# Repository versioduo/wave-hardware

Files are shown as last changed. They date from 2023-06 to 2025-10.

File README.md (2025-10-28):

# wave-hardware
🔊 MA12070P Class-D Amplifier

## Board

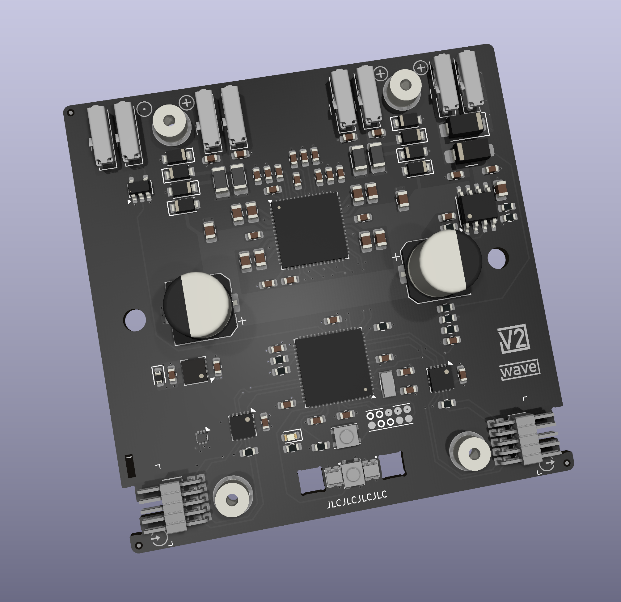
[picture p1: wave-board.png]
wave


## Schematic

[PDF](wave.pdf)

## Bill Of Materials

[Interactive BOM](https://htmlpreview.github.io/?https://github.com/versioduo/wave-hardware/main/wave-bom.html)

# Copying
Anyone can use this public domain work without having to seek authorisation, no one can ever own it.

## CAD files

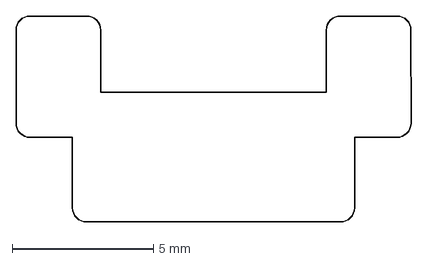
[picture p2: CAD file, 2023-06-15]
button-laser.dxf
14.0 x 7.30 mm

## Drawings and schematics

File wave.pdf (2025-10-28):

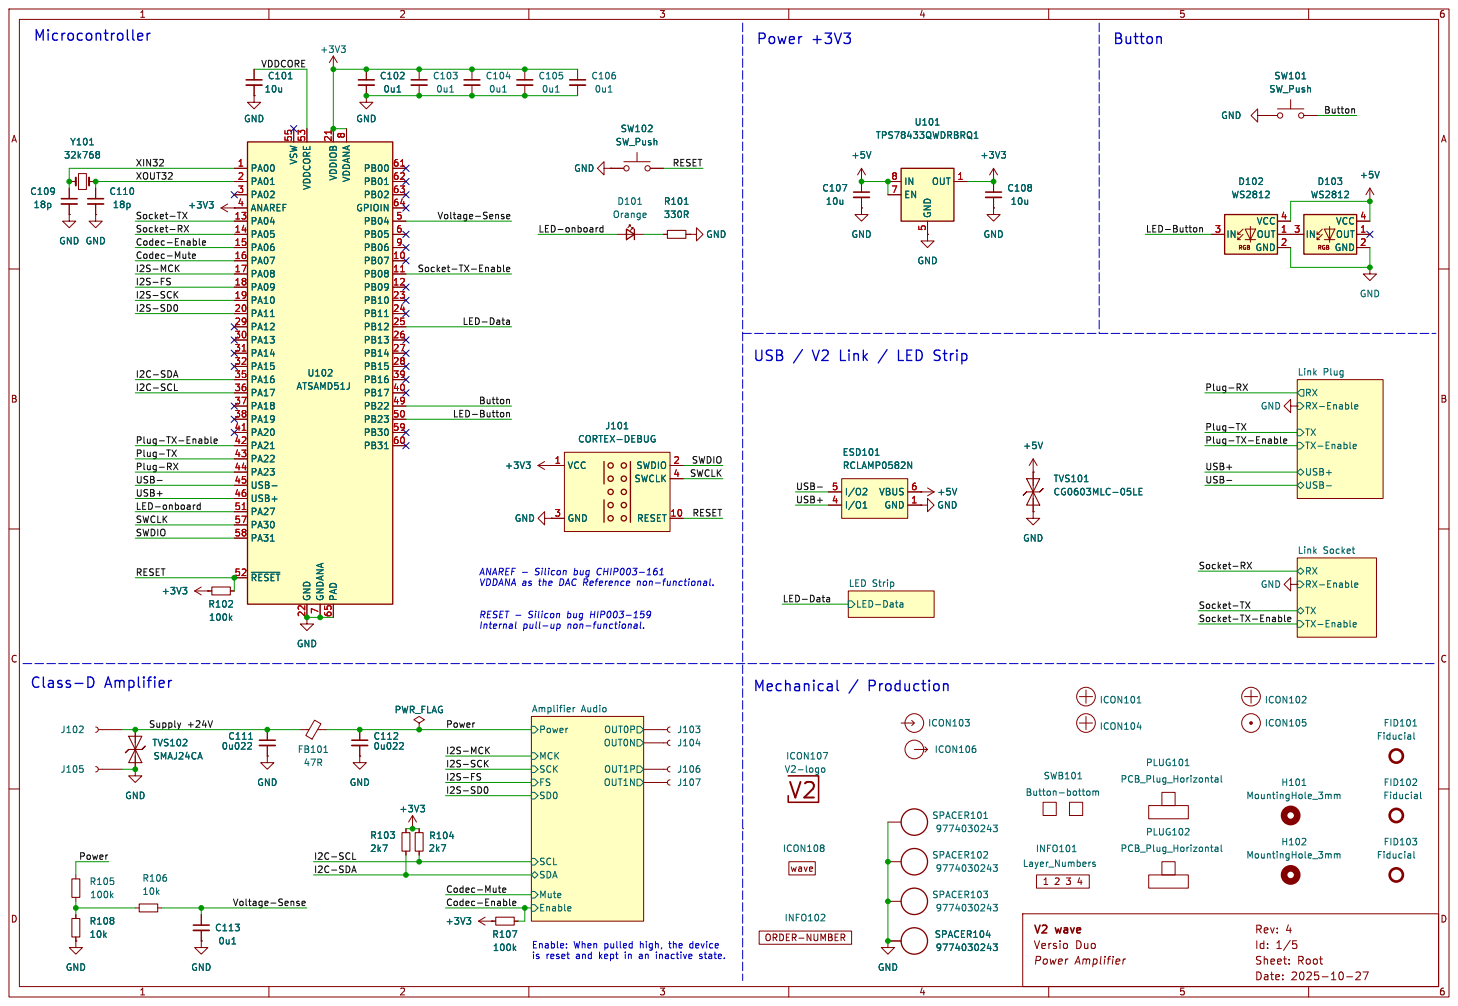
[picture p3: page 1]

LED-Data Socket-TX-Enable XIN32 XOUT32 Codec-Enable Socket-RX USB- Socket-TX USB+ Plug-RX

LED-Button Codec-Enable

Link Plug TXRXRX-Enable TX-Enable
USB+ USB- RX
TXRX-Enable TX-Enable

Plug-RX USB- SWDIO

Plug-TX USB+ RESET

Link Socket LED-Data

LED Strip Enable Mute SCL FS

Enable: When pulled high, the device

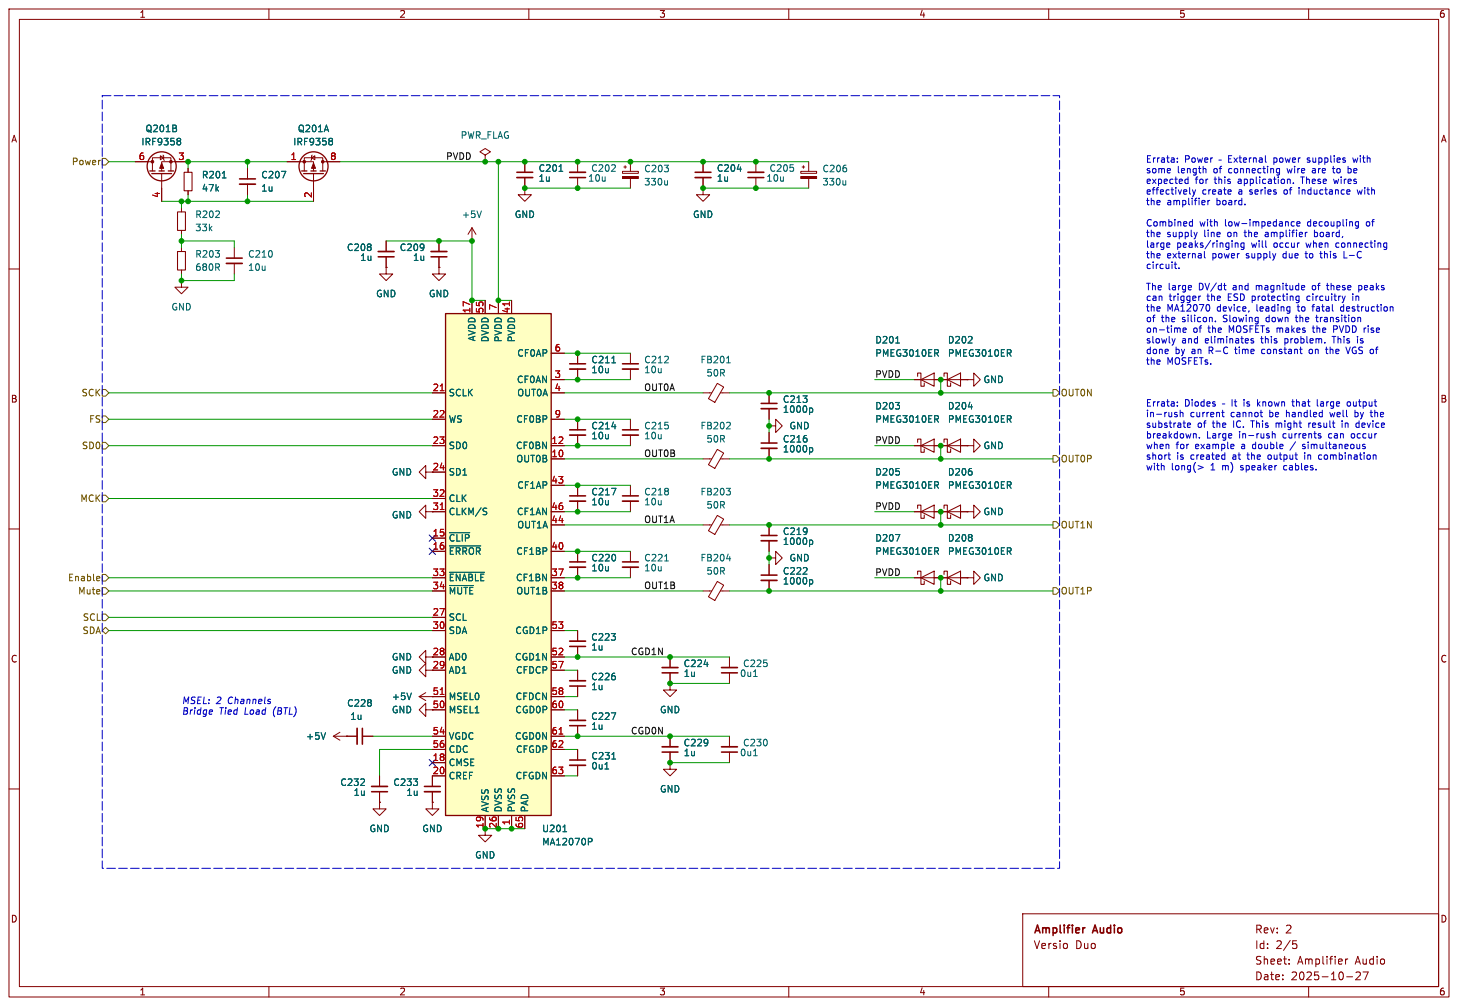
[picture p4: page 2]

PVDD MSEL: 2 Channels Bridge Tied Load (BTL)

the MA12070 device, leading to fatal destruction

1 PAD 65 CF0AP 6 CF0AN 3 OUT0A 4 CF0BP 9 CF0BN 12 OUT0B 10 CF1AP 43 CF1AN 46 OUT1A 44 CF1BP 40 CF1BN 37 OUT1B 38 CGD1P 53 CGD1N 52 CFDCP 57 CFDCN 58 CGD0P 60 CGD0N 61 CFGDP 62 CFGDN 63 C232

1 PAD 65 CF0AP 6 CF0AN 3 OUT0A 4 CF0BP 9 CF0BN 12 OUT0B 10 CF1AP 43 CF1AN 46 OUT1A 44 CF1BP 40 CF1BN 37 OUT1B 38 CGD1P 53 CGD1N 52 CFDCP 57 CFDCN 58 CGD0P 60 CGD0N 61 CFGDP 62 CFGDN 63 U201 MA12070P C233

the MOSFETs. Errata: Diodes þÿ It is known that large output

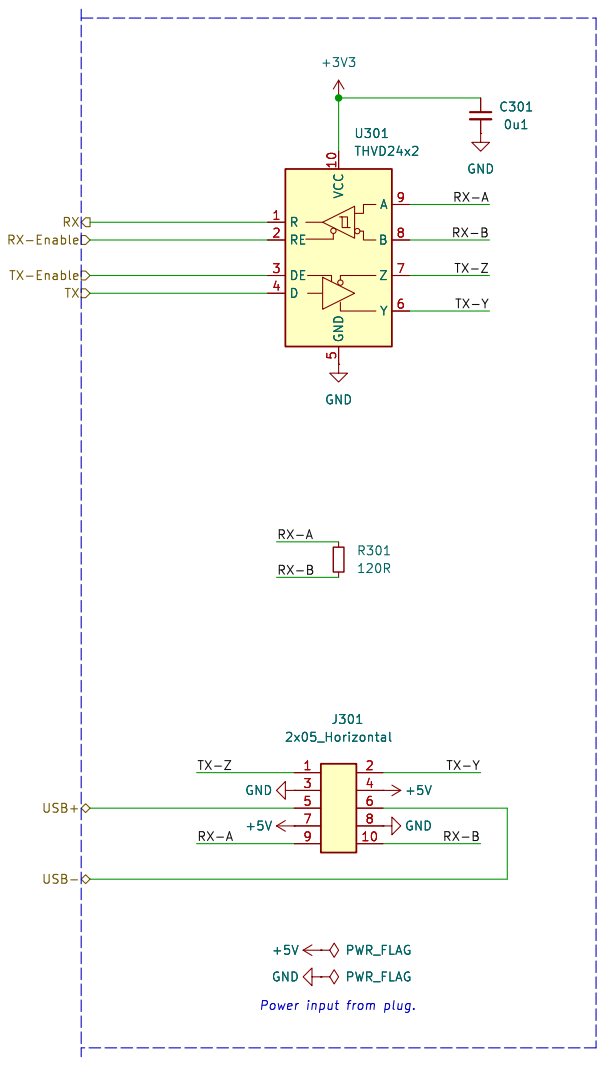
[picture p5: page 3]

Power input from plug. +5V GND GND

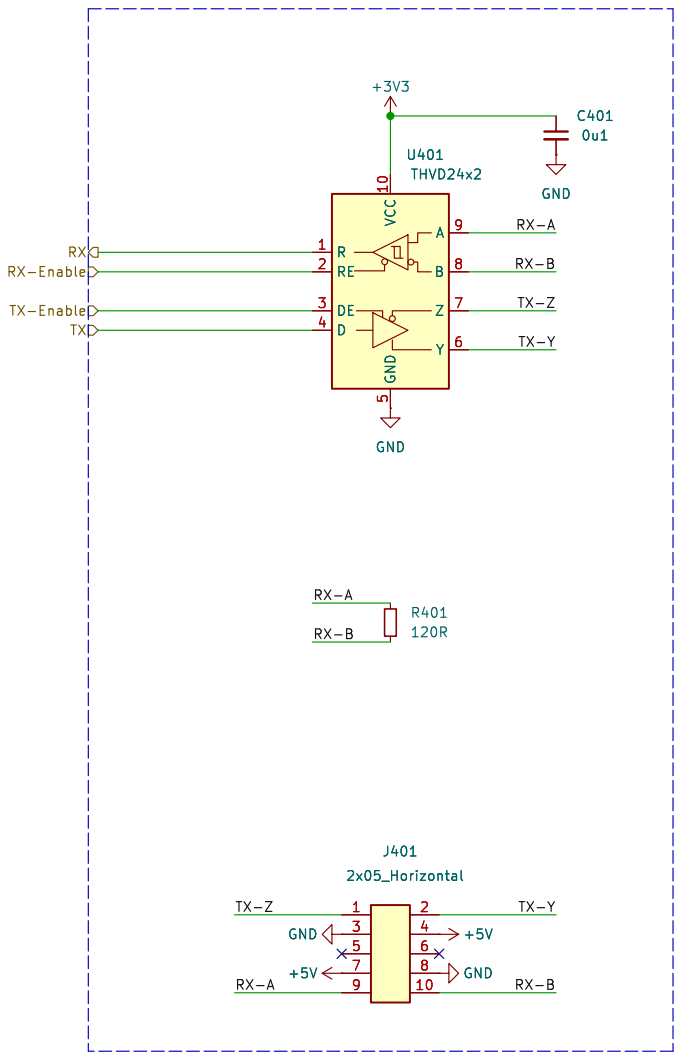
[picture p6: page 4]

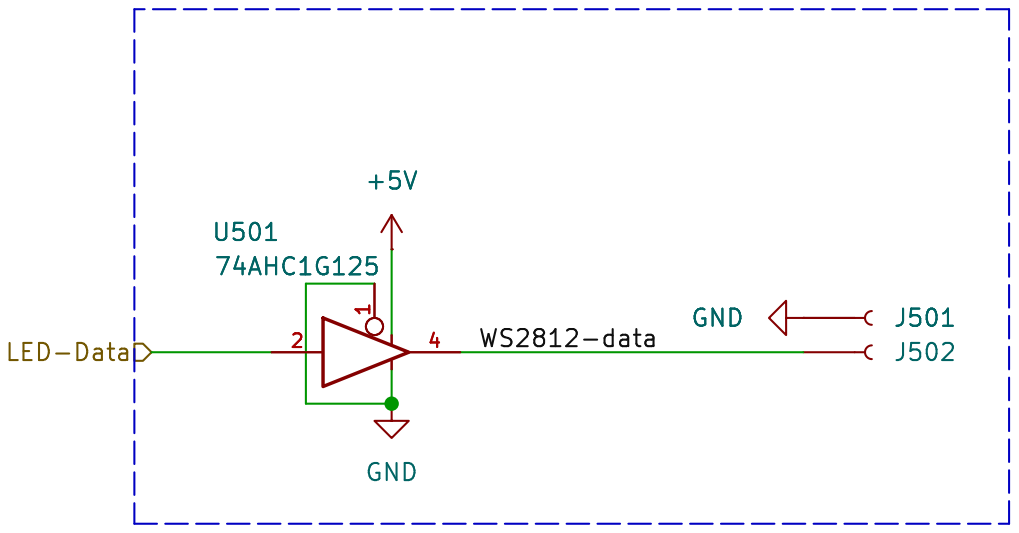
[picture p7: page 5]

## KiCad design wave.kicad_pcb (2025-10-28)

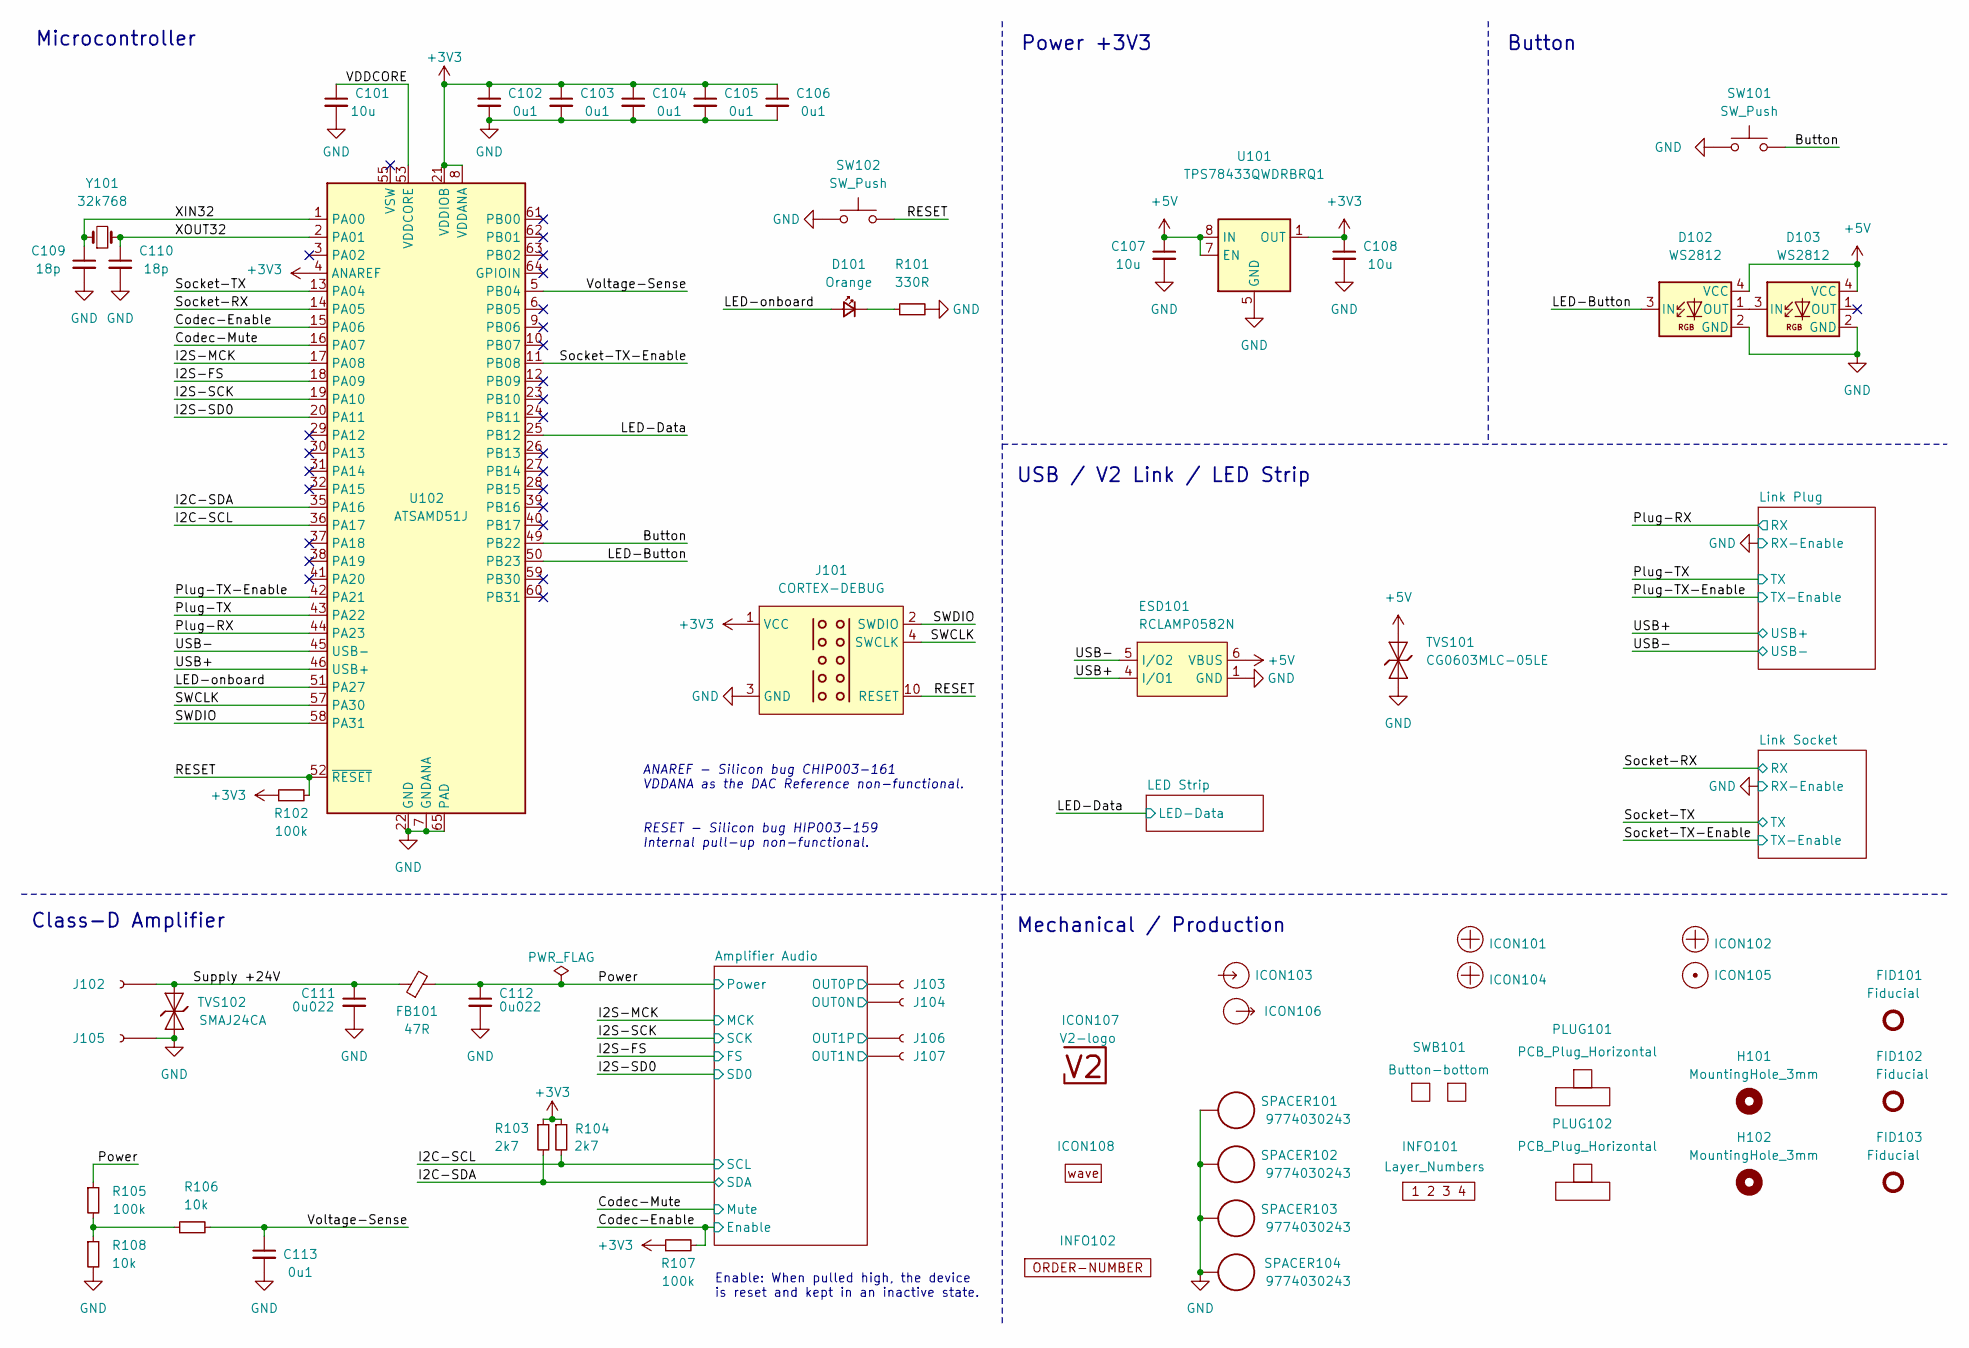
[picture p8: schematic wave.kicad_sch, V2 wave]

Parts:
C101, C107, C108: 10u; C_0603_1608Metric
C102, C103, C104, C105, C106, C113: 0u1; C_0603_1608Metric
C109, C110: 18p; C_0603_1608Metric
C111, C112: 0u022; C_0603_1608Metric
D101: Orange; LED_0603_1608Metric
D102, D103: WS2812; WS2812-2020
ESD101: RCLAMP0582N; SLP1210N6
FB101: 47R; L_3.1x5.1
FID101, FID102, FID103: Fiducial; Fiducial_0.5mm_Mask1mm_Paste
H101, H102: MountingHole_3mm
ICON101, ICON102, ICON104: Plus; Plus_Small
ICON103: Arrow_In
ICON105: Dot; Dot_Small
ICON106: Arrow_Out
ICON107: V2-logo; Logo_Small
ICON108: Board_wave; Board_wave_Small
INFO101: Layer_Numbers
INFO102: ORDER-NUMBER; Order_Number
J101: CORTEX-DEBUG; Cortex_Debug_Pad
J102, J103, J104, J105, J106, J107: WAGO-2065; 2065-100
PLUG101, PLUG102: PCB_Plug_Horizontal
R101: 330R; R_0603_1608Metric
R102, R105, R107: 100k; R_0603_1608Metric
R103, R104: 2k7; R_0603_1608Metric
R106, R108: 10k; R_0603_1608Metric
SPACER101, SPACER102, SPACER103, SPACER104: 9774030243
SW101, SW102: SW_Push; SKSG
SWB101: Button-bottom; PCB_Button-bottom
TVS101: CG0603MLC-05LE; D_0603_1608Metric
TVS102: SMAJ24CA; D_SMA
U101: TPS78433QWDRBRQ1; VSON-8-1_3x3mm_P0.65_EP1.65x2.4mm
U102: ATSAMD51J; QFN-64-1EP_9x9mm_P0.5mm_EP4.8x4.8mm_ThermalVias
Y101: 32k768; Crystal_SMD_3215-2Pin_3.2x1.5mm

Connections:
+3V3: C102.1, C103.1, C104.1, C105.1, C106.1, C108.1, J101.1 (VCC), R102.1, R103.1, R104.1, R107.1, U101.1 (OUT), U102.4 (ANAREF), U102.8 (VDDANA), U102.21 (VDDIOB), U102.34 (VDDIO), U102.48 (VDDIO), U102.56 (VDDIO); also elsewhere on the board
+5V: C107.1, D102.4 (VCC), D103.4 (VCC), ESD101.6 (VBUS), TVS101.2 (A), U101.7 (EN), U101.8 (IN); also elsewhere on the board
/Amplifier Audio/OUT0N: J104.1; also elsewhere on the board
/Amplifier Audio/OUT0P: J103.1; also elsewhere on the board
/Amplifier Audio/OUT1N: J107.1; also elsewhere on the board
/Amplifier Audio/OUT1P: J106.1; also elsewhere on the board
/Button: SW101.2, U102.49 (PB22)
/Codec-Enable: R107.2, U102.15 (PA06); also elsewhere on the board
/Codec-Mute: U102.16 (PA07); also elsewhere on the board
/I2C-SCL: R104.2, U102.36 (PA17); also elsewhere on the board
/I2C-SDA: R103.2, U102.35 (PA16); also elsewhere on the board
/I2S-FS: U102.18 (PA09); also elsewhere on the board
/I2S-MCK: U102.17 (PA08); also elsewhere on the board
/I2S-SCK: U102.19 (PA10); also elsewhere on the board
/I2S-SD0: U102.20 (PA11); also elsewhere on the board
/LED-Button: D102.3 (IN), U102.50 (PB23)
/LED-Data: U102.25 (PB12); also elsewhere on the board
/LED-onboard: D101.2 (A), U102.51 (PA27)
/Plug-RX: U102.44 (PA23); also elsewhere on the board
/Plug-TX: U102.43 (PA22); also elsewhere on the board
/Plug-TX-Enable: U102.42 (PA21); also elsewhere on the board
/Power: C112.1, FB101.2, R105.1; also elsewhere on the board
/RESET: J101.10 (RESET), R102.2, SW102.2, U102.52 (~RESET)
/SWCLK: J101.4 (SWCLK), U102.57 (PA30)
/SWDIO: J101.2 (SWDIO), U102.58 (PA31)
/Socket-RX: U102.14 (PA05); also elsewhere on the board
/Socket-TX: U102.13 (PA04); also elsewhere on the board
/Socket-TX-Enable: U102.11 (PB08); also elsewhere on the board
/Supply +24V: C111.1, FB101.1, J102.1, TVS102.2 (A)
/USB+: ESD101.4 (I/O1), U102.46 (USB+); also elsewhere on the board
/USB-: ESD101.5 (I/O2), U102.45 (USB-); also elsewhere on the board
/VDDCORE: C101.1, U102.53 (VDDCORE)
/Voltage-Sense: C113.1, R106.2, U102.5 (PB04)
/XIN32: C109.1, U102.1 (PA00), Y101.1
/XOUT32: C110.1, U102.2 (PA01), Y101.2
GND: C101.2, C102.2, C103.2, C104.2, C105.2, C106.2, C107.2, C108.2, C109.2, C110.2, C111.2, C112.2, C113.2, D102.2 (GND), D103.2 (GND), ESD101.1 (GND), J101.3 (GND), J101.5 (GND), J105.1, R101.2, R108.2, SPACER101.1, SPACER102.1, SPACER103.1, SPACER104.1, SW101.1, SW102.1, TVS101.1 (K), TVS102.1 (K), U101.5 (GND), U101.9 (GND), U102.7 (GNDANA), U102.22 (GND), U102.33 (GND), U102.47 (GND), U102.54 (GND), U102.65 (PAD); also elsewhere on the board
unnamed: D101.1 (K), R101.1
unnamed: D102.1 (OUT), D103.3 (IN)
unnamed: R105.2, R106.1, R108.1

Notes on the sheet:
 ANAREF - Silicon bug CHIP003-161 VDDANA as the DAC Reference non-functional.
RESET -  Silicon bug HIP003-159 Internal pull-up non-functional.
Button
USB / V2 Link / LED Strip
Mechanical / Production
Power +3V3
Enable: When pulled high, the device is reset and kept in an inactive state.
Microcontroller
Class-D Amplifier

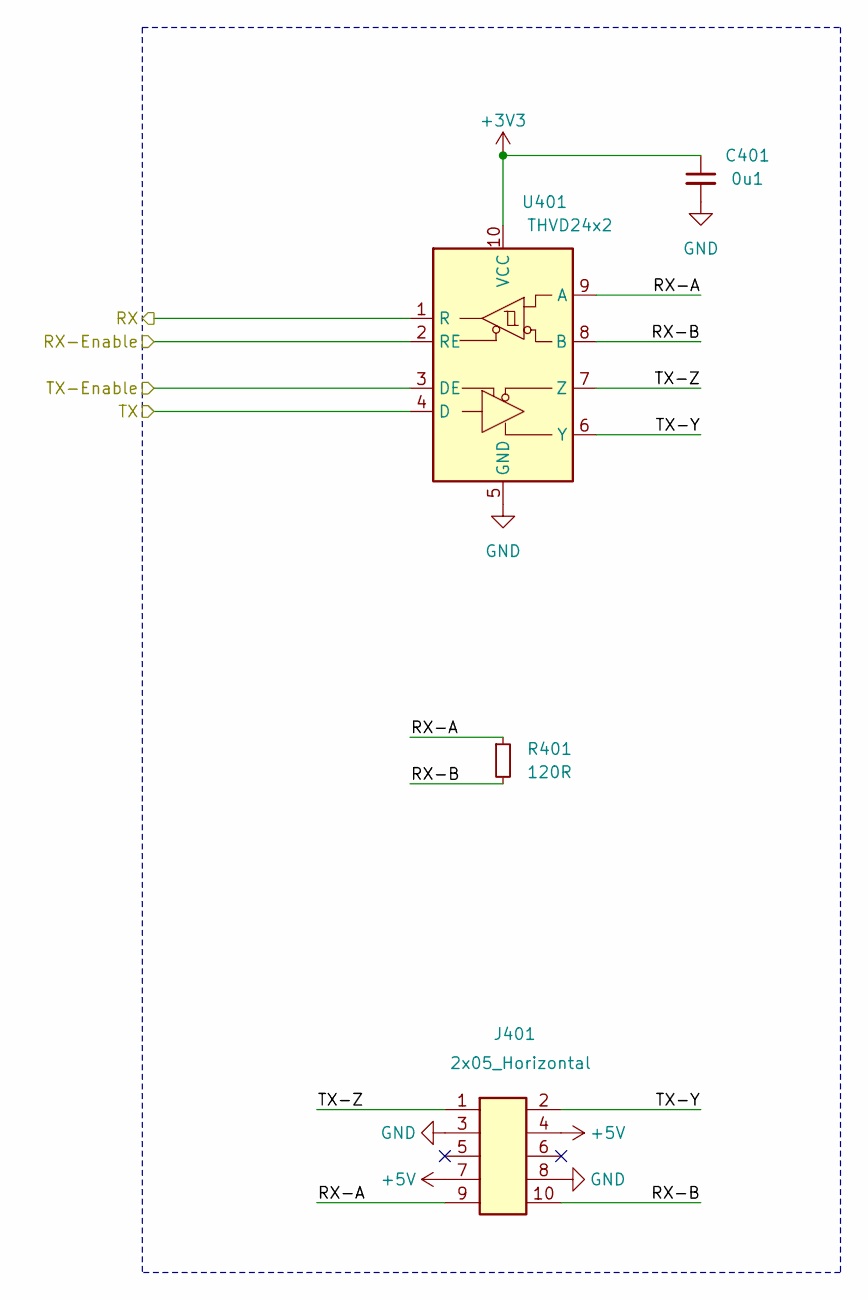
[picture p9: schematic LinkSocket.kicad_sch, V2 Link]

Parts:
C401: 0u1; C_0603_1608Metric
J401: 2x05_Horizontal; PinHeader_2x05_P1.27mm_Horizontal
R401: 120R; R_0603_1608Metric
U401: THVD24x2; VSON-10-4-1EP_3x3mm_P0.5mm_EP1.65x2.4mm_ThermalVias

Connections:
+3V3: C401.1, U401.10 (VCC); also elsewhere on the board
+5V: J401.4, J401.7; also elsewhere on the board
/Link Socket/RX-A: J401.9, R401.1, U401.9 (A)
/Link Socket/RX-B: J401.10, R401.2, U401.8 (B)
/Link Socket/TX-Y: J401.2, U401.6 (Y)
/Link Socket/TX-Z: J401.1, U401.7 (Z)
/Socket-RX: U401.1 (R); also elsewhere on the board
/Socket-TX: U401.4 (D); also elsewhere on the board
/Socket-TX-Enable: U401.3 (DE); also elsewhere on the board
GND: C401.2, J401.3, J401.8, U401.2 (RE), U401.5 (GND), U401.11 (GND); also elsewhere on the board

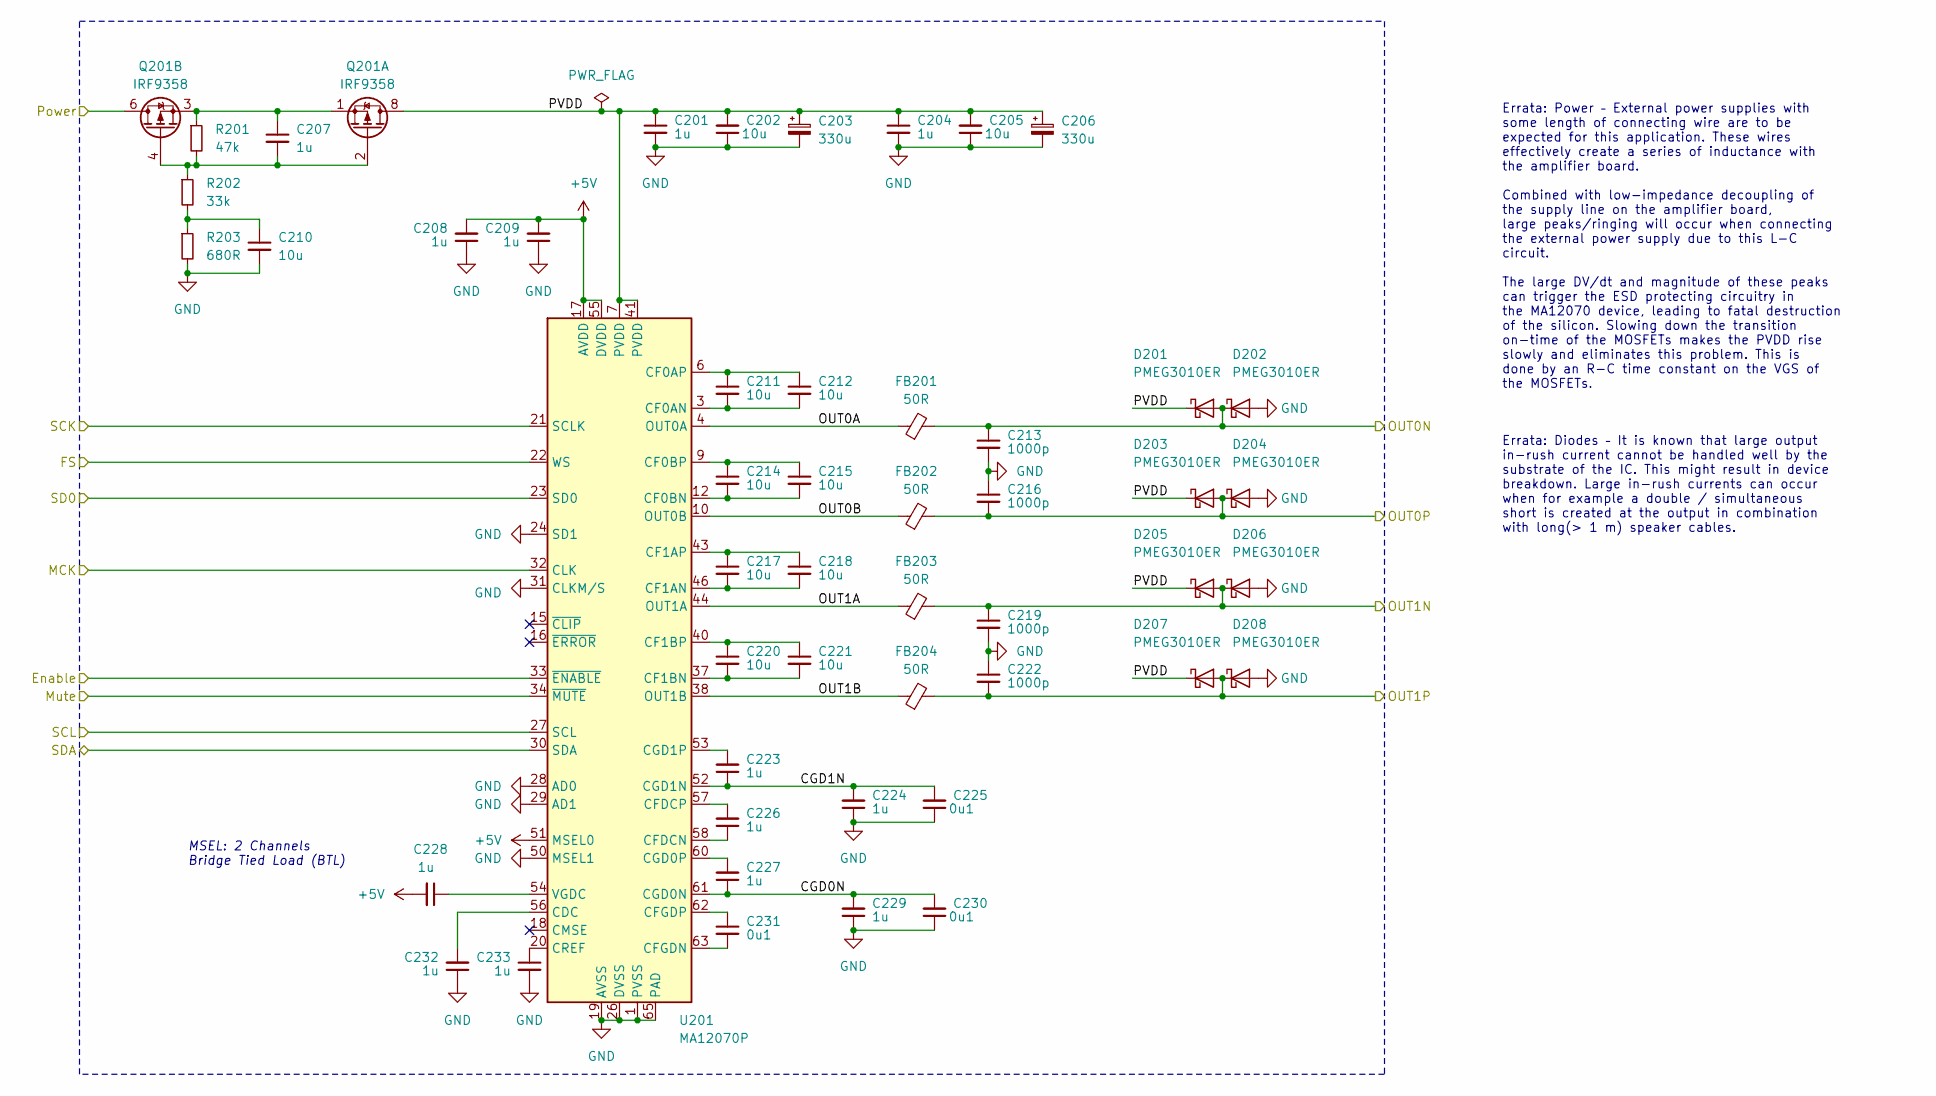
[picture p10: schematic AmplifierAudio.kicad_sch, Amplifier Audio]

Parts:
C201, C204, C207, C208, C209, C223, C224, C226, C227, C228, C229, C232, C233: 1u; C_0603_1608Metric
C202, C205, C210, C211, C212, C214, C215, C217, C218, C220, C221: 10u; C_0805_2012Metric
C203, C206: 330u; CP_Elec_8x10
C213, C216, C219, C222: 1000p; C_0603_1608Metric
C225, C230, C231: 0u1; C_0603_1608Metric
D201, D202, D203, D204, D205, D206, D207, D208: PMEG3010ER; Nexperia_CFP3_SOD-123W
FB201, FB202, FB203, FB204: 50R; L_1206_3216Metric
Q201: IRF9358; SOIC-8_3.9x4.9mm_P1.27mm
R201: 47k; R_0603_1608Metric
R202: 33k; R_0603_1608Metric
R203: 680R; R_0603_1608Metric
U201: MA12070P; QFN-64-1EP_9x9mm_P0.5mm_EP5.45x5.45mm_ThermalVias

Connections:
+5V: C208.2, C209.2, C228.2, U201.17 (AVDD), U201.51 (MSEL0), U201.55 (DVDD); also elsewhere on the board
/Amplifier Audio/CGD0N: C227.1, C229.2, C230.2, U201.61 (CGD0N)
/Amplifier Audio/CGD1N: C223.1, C224.2, C225.2, U201.52 (CGD1N)
/Amplifier Audio/OUT0A: FB201.1, U201.4 (OUT0A), U201.5 (OUT0A)
/Amplifier Audio/OUT0B: FB202.1, U201.10 (OUT0B), U201.11 (OUT0B)
/Amplifier Audio/OUT0N: C213.1, D201.2 (A), D202.1 (K), FB201.2; also elsewhere on the board
/Amplifier Audio/OUT0P: C216.2, D203.2 (A), D204.1 (K), FB202.2; also elsewhere on the board
/Amplifier Audio/OUT1A: FB203.1, U201.44 (OUT1A), U201.45 (OUT1A)
/Amplifier Audio/OUT1B: FB204.1, U201.38 (OUT1B), U201.39 (OUT1B)
/Amplifier Audio/OUT1N: C219.1, D205.2 (A), D206.1 (K), FB203.2; also elsewhere on the board
/Amplifier Audio/OUT1P: C222.2, D207.2 (A), D208.1 (K), FB204.2; also elsewhere on the board
/Amplifier Audio/PVDD: C201.1, C202.2, C203.1, C204.1, C205.2, C206.1, D201.1 (K), D203.1 (K), D205.1 (K), D207.1 (K), Q201.7 (D1), Q201.8 (D1), U201.7 (PVDD), U201.8 (PVDD), U201.41 (PVDD), U201.42 (PVDD)
/Codec-Enable: U201.33 (~ENABLE); also elsewhere on the board
/Codec-Mute: U201.34 (~MUTE); also elsewhere on the board
/I2C-SCL: U201.27 (SCL); also elsewhere on the board
/I2C-SDA: U201.30 (SDA); also elsewhere on the board
/I2S-FS: U201.22 (WS); also elsewhere on the board
/I2S-MCK: U201.32 (CLK); also elsewhere on the board
/I2S-SCK: U201.21 (SCLK); also elsewhere on the board
/I2S-SD0: U201.23 (SD0); also elsewhere on the board
/Power: Q201.5 (D2), Q201.6 (D2); also elsewhere on the board
GND: C201.2, C202.1, C203.2, C204.2, C205.1, C206.2, C208.1, C209.1, C210.2, C213.2, C216.1, C219.2, C222.1, C224.1, C225.1, C229.1, C230.1, C232.1, C233.2, D202.2 (A), D204.2 (A), D206.2 (A), D208.2 (A), R203.2, U201.1 (PVSS), U201.2 (PVSS), U201.13 (PVSS), U201.14 (PVSS), U201.19 (AVSS), U201.24 (SD1), U201.25 (AVSS), U201.26 (DVSS), U201.28 (AD0), U201.29 (AD1), U201.31 (CLKM/S), U201.35 (PVSS), U201.36 (PVSS), U201.47 (PVSS), U201.48 (PVSS), U201.50 (MSEL1), U201.59 (DVSS), U201.65 (PAD); also elsewhere on the board
unnamed: C210.1, R202.2, R203.1
unnamed: C207.2, Q201.2 (G1), Q201.4 (G2), R201.2, R202.1
unnamed: C207.1, Q201.1 (S1), Q201.3 (S2), R201.1
unnamed: C232.2, U201.56 (CDC)
unnamed: C211.2, C212.2, U201.3 (CF0AN)
unnamed: C211.1, C212.1, U201.6 (CF0AP)
unnamed: C214.2, C215.2, U201.12 (CF0BN)
unnamed: C214.1, C215.1, U201.9 (CF0BP)
unnamed: C217.2, C218.2, U201.46 (CF1AN)
unnamed: C217.1, C218.1, U201.43 (CF1AP)
unnamed: C220.2, C221.2, U201.37 (CF1BN)
unnamed: C220.1, C221.1, U201.40 (CF1BP)
unnamed: C226.1, U201.58 (CFDCN)
unnamed: C226.2, U201.57 (CFDCP)
unnamed: C231.2, U201.63 (CFGDN)
unnamed: C231.1, U201.62 (CFGDP)
unnamed: C227.2, U201.60 (CGD0P)
unnamed: C223.2, U201.53 (CGD1P)
unnamed: C233.1, U201.20 (CREF)
unnamed: C228.1, U201.54 (VGDC)

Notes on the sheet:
Errata: Diodes – It is known that large output in-rush current cannot be handled well by the substrate of the IC. This might result in device breakdown. Large in-rush currents can occur when for example a double / simultaneous short is created at the output in combination with long(> 1 m) speaker c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
MSEL: 2 Channels Bridge Tied Load (BTL)
Errata: Power – External power supplies with some length of connecting wire are to be expected for this application. These wires effectively create a series of inductance with the amplifier board. Combined with low-impedance decoupling of the supply line on the amplifier board, large peaks/ringing 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

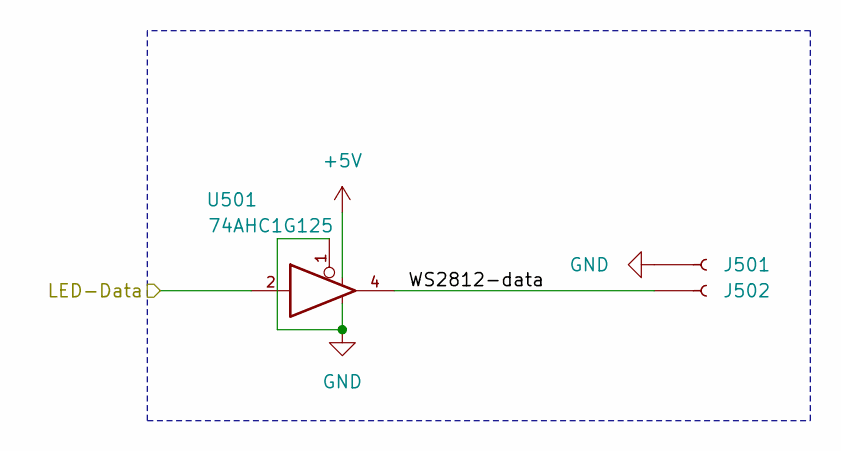
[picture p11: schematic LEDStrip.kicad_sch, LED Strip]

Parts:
J501, J502: WAGO-2065; 2065-100
U501: 74AHC1G125; SOT-23-5

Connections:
+5V: U501.5; also elsewhere on the board
/LED Strip/WS2812-data: J502.1, U501.4
/LED-Data: U501.2; also elsewhere on the board
GND: J501.1, U501.1, U501.3; also elsewhere on the board

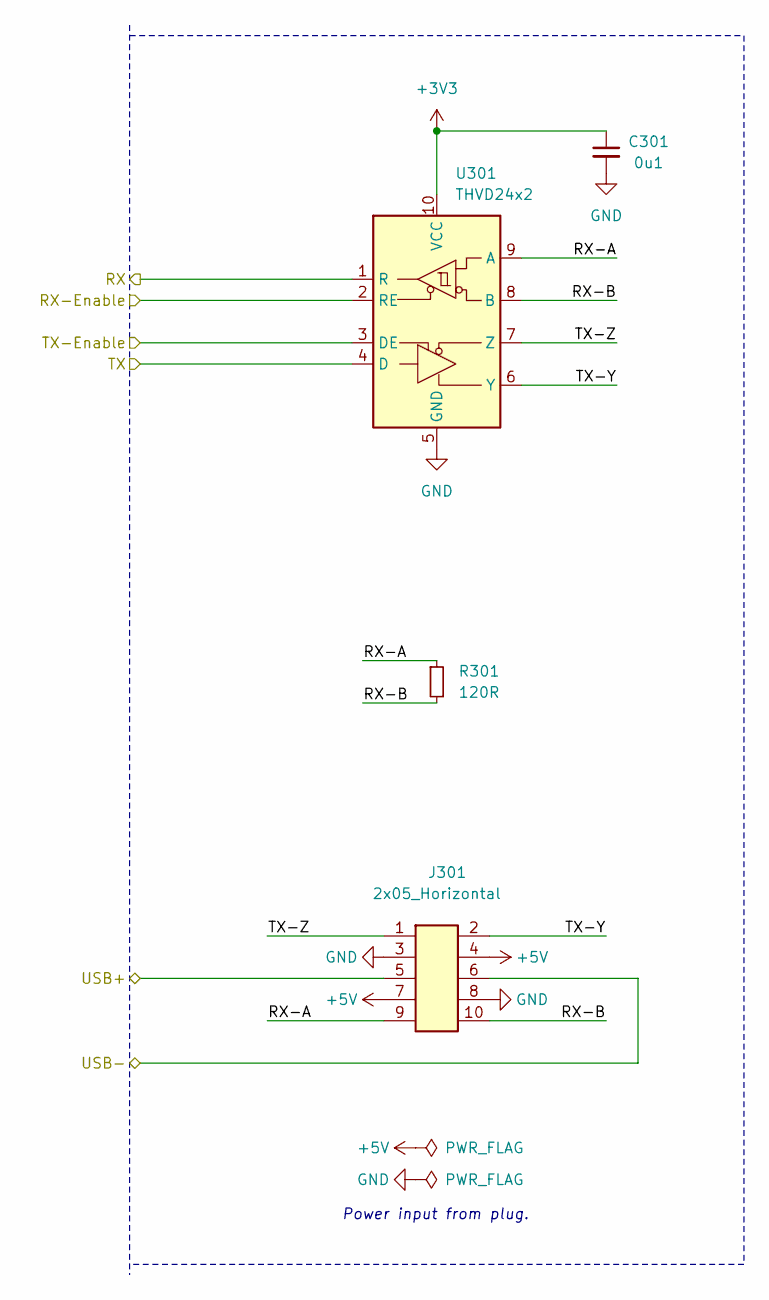
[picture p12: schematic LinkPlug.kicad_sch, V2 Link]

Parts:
C301: 0u1; C_0603_1608Metric
J301: 2x05_Horizontal; PinHeader_2x05_P1.27mm_Horizontal
R301: 120R; R_0603_1608Metric
U301: THVD24x2; VSON-10-4-1EP_3x3mm_P0.5mm_EP1.65x2.4mm_ThermalVias

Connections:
+3V3: C301.1, U301.10 (VCC); also elsewhere on the board
+5V: J301.4, J301.7; also elsewhere on the board
/Link Plug/RX-A: J301.9, R301.1, U301.9 (A)
/Link Plug/RX-B: J301.10, R301.2, U301.8 (B)
/Link Plug/TX-Y: J301.2, U301.6 (Y)
/Link Plug/TX-Z: J301.1, U301.7 (Z)
/Plug-RX: U301.1 (R); also elsewhere on the board
/Plug-TX: U301.4 (D); also elsewhere on the board
/Plug-TX-Enable: U301.3 (DE); also elsewhere on the board
/USB+: J301.5; also elsewhere on the board
/USB-: J301.6; also elsewhere on the board
GND: C301.2, J301.3, J301.8, U301.2 (RE), U301.5 (GND), U301.11 (GND); also elsewhere on the board

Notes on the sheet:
Power input from plug.

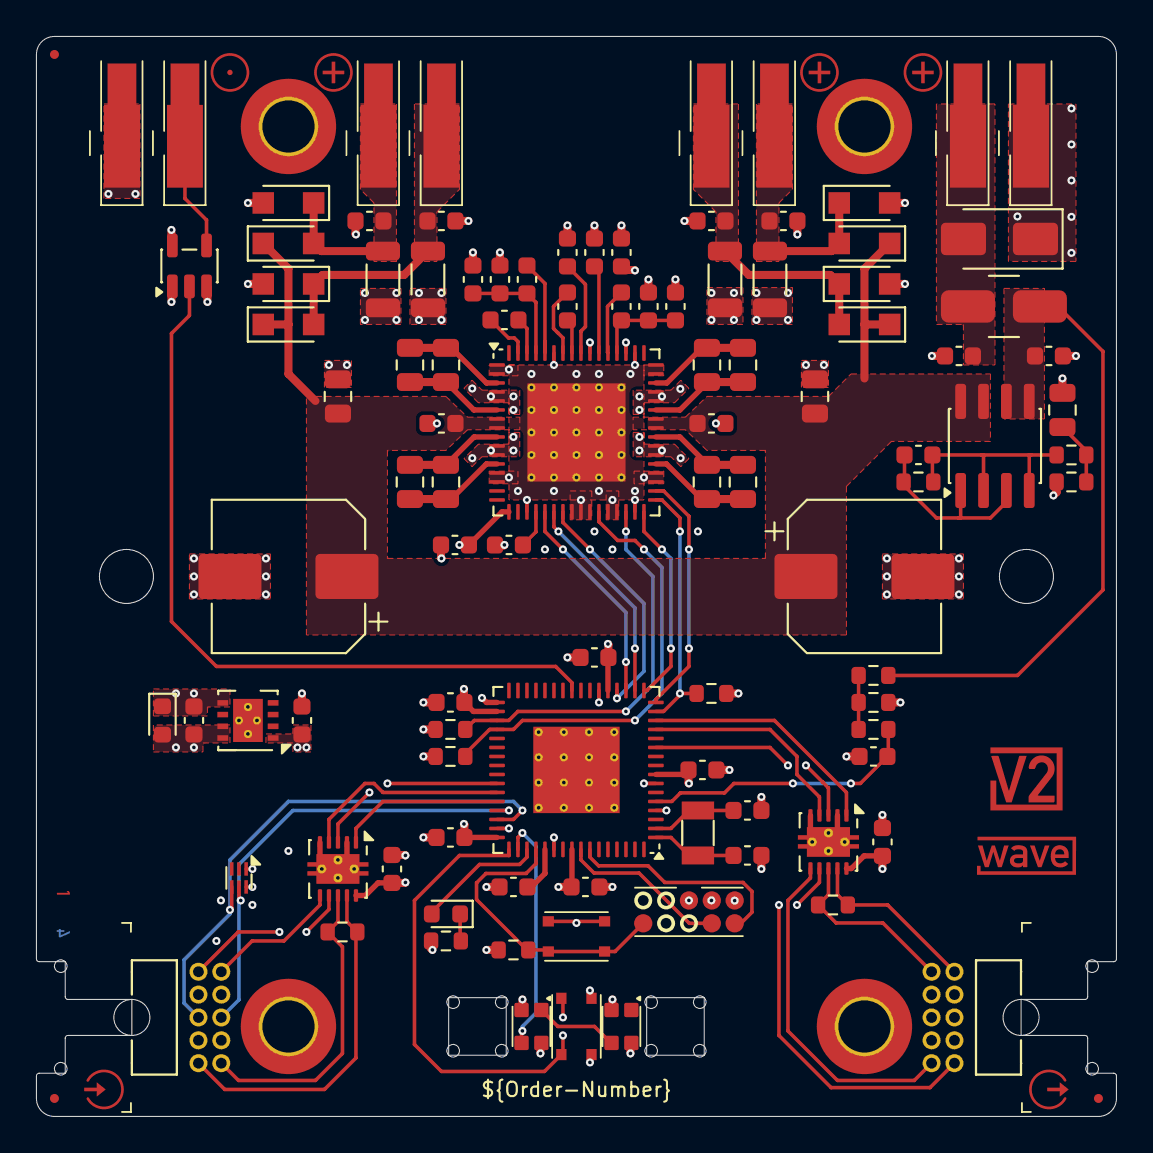
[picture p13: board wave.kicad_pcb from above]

Board: 4 copper layers, 60.0 x 60.0 mm, 123 parts (0 on the bottom side), 75 nets.

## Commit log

2024-03-28 Update to Kicad 8
    [AmplifierAudio.kicad_sch, LEDStrip.kicad_sch, LinkPlug.kicad_sch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]
2024-06-20 Replace icons
    [AmplifierAudio.kicad_sch, LEDStrip.kicad_sch, LinkPlug.kicad_sch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]
